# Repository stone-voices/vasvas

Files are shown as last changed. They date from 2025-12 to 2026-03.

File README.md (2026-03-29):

# VasVas Noisebox

Noisebox with FX Processor based on Daisy Seed microcontroller. 

Demo Video (https://www.youtube.com/watch?v=F5kSkdeNpbo)

This noise box has two piezo pickups, the signal from which falls into the left and right channels, respectively, which allows you to get a real stereo signal at the output. In firmware version 1.0, the effects processor includes a reverb based on the Dattorro algorithm and a Shimmer effect that extracts the second harmonic from the signal. A special feature of the reverb is the presence of delay lines and all-pass filters with proportionally variable sizes, as well as a long decay, which can be switched to freezing mode to obtain an undamped reverberation.
In future versions, some changes in the effects used are possible, although this will only affect the software, leaving the hardware unchanged.

This repository includes the circuit diagram and KiCad design files for the PCB, as well as the source code, including all the libraries needed for building.

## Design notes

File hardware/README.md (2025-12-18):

# Hardware

This directory contains the KiCad files for manufacturing the VasVas Noisebox PCB. Includes schematic, pcb, and BOM.

## VasVas Noisebox base

The VasVas Noisebox base uses a plywood case with the following characteristics:
- Stereo output as two separate jacks. One of them can be used as a stereo (left channel) if the right channel jack is not connected.
- 9..15v power
- 4 potentiometer knobs 
- 1 push button
- 2 LEDs

As for the elements that create mechanical vibrations, you can use them at your discretion. These can be compression and tension springs, various plates, gongs, tuning forks, spinners, radiators and other sources of vibrations. Appropriate fasteners must also be used to secure these elements in the form of bolts, nuts, washers, self-tapping screws, etc.

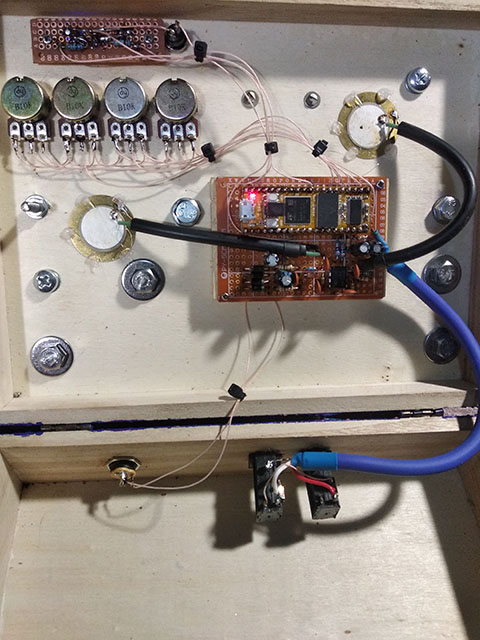
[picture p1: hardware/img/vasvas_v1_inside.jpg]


The electrical circuits are mounted by soldering using a MGTF mounting wire (stranded copper wire with fluoroplastic insulation) with a cross section of 0.07 square mm. The output connectors and piezoelectric elements are connected by a shielded wire to reduce interference. The piezoelectric elements are attached to the body by gluing with an adhesive gun with nylon rods.

The prototype was assembled using a 70 x 50 mm breadboard.

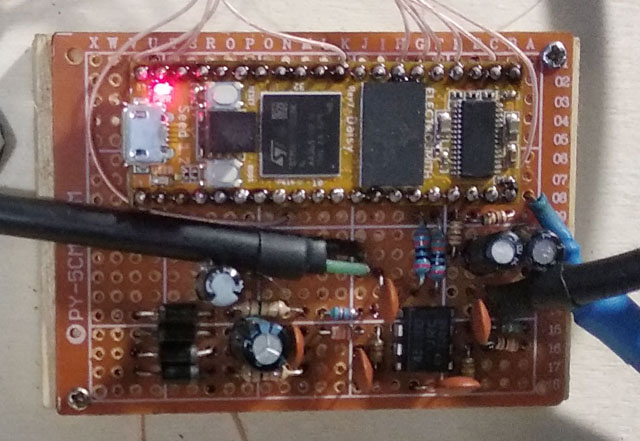
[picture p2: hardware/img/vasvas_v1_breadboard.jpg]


The LEDs, together with current-limiting resistors, are mounted on a small piece of a breadboard.

The layout of the elements is very arbitrary, so you can change it at your discretion based on your needs.

### Some remarks

You can change the schematic diagram of the pre-amplification stage by changing the brand of the operational amplifier to a higher-quality one, or abandon it altogether by replacing it with an amplification stage on a field-effect or bipolar transistor.

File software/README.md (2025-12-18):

# Software

Software for the VasVas Noisebox platform.
So far only version 1.0.

Compilation and assembly was carried out in Visual Studio Code.

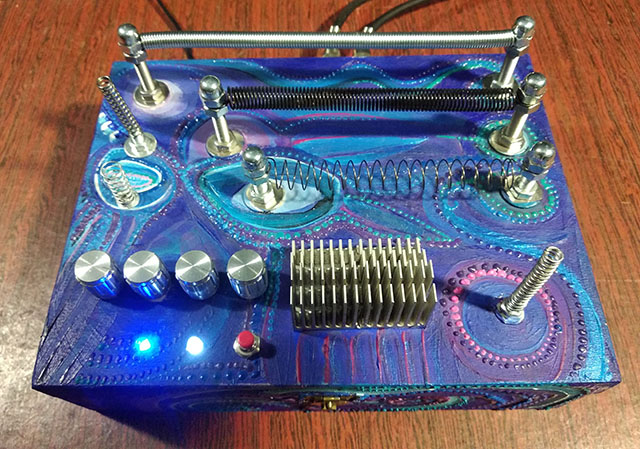
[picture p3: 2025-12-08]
hardware/img/vasvas_v1_front.jpg

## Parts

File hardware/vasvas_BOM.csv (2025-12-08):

Item | Reference(s) | Value
1 | A1 | Electrosmith Daisy Seed Rev7
2 | J4/J5 | 01x20 Socket or DIP40 Socket 15.24mm 2.54mm
3 | U1 | 4580DD
4 | Y1 | Piezo disk 27mm
5 | Y2 | Piezo disk 27mm
6 | HL1 | LED blue
7 | HL2 | LED white
8 | SW1 | Button ST-304B
9 | J1 | Power Jack DC 5.5 x 2.5
10 | J2 | Audio Jack stereo 6.3 mm
11 | J3 | Audio Jack stereo 6.3 mm
12 | RV1 | Potentiometer 10K B
13 | RV2 | Potentiometer 10K B
14 | RV3 | Potentiometer 10K B
15 | RV4 | Potentiometer 10K B
16 | R1 | Resistor 0.125w 10K
17 | R2 | Resistor 0.125w 10K
18 | R3 | Resistor 0.125w 100K
19 | R4 | Resistor 0.125w 100K
20 | R5 | Resistor 0.125w 10K
21 | R6 | Resistor 0.125w 10K
22 | R7 | Resistor 0.125w 100K
23 | R8 | Resistor 0.125w 100K
24 | R9 | Resistor 0.125w 100K
25 | R10 | Resistor 0.125w 100K
26 | R11 | Resistor 0.125w 510
27 | R12 | Resistor 0.125w 510
28 | R13 | Resistor 0.125w 220
29 | R14 | Resistor 0.125w 220
30 | C1 | Electrolytic capacitor 100µFx25v
31 | C2 | Ceramic capacitor 100nF
32 | C3 | Electrolytic capacitor 100µFx16v
33 | C4 | Ceramic capacitor 100nF
34 | C5 | Ceramic capacitor 100nF
35 | C6 | Ceramic capacitor 100nF
36 | C7 | Ceramic capacitor 100nF
37 | C8 | Electrolytic capacitor 22µFx16v BP
38 | C9 | Electrolytic capacitor 22µFx16v BP
39 | D1 | 1N4004
40 | D2 | 1N4004
41 | D3 | 1N4004
42 | D4 | 1N4004

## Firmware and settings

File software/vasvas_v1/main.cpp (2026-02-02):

#include "daisy_petal.h"
#include "daisysp.h"

#include "tools.h"
#include "reverb.h"
#include "fastsin.h"
#include <q/support/literals.hpp>
#include <q/fx/biquad.hpp>
#include "multirate.h"
#include "octaver.h"

#define BUFFER_SIZE 48
#define LED_1 22
#define FOOTSWITCH_1 0
#define FOOTSWITCH_2 1
#define KNOB_1 4
#define	KNOB_2 2
#define	KNOB_3 0
#define	KNOB_4 1

namespace q = cycfi::q;
using namespace q::literals;

using namespace daisy;
using namespace daisysp;


DaisyPetal hw;
Parameter rsize, mix, rdecay, shimmer;
float psize, pmix, pdecay, pshimmer;
float vmix, vdecay, vsize, vshimmer;
Led led1;

float dryMix = 1;
float wetMix = 0;

TReverb reverb;

bool freeze = false;

static const auto sample_rate_temp = 48000; //hard code for now 
static Decimator2 decimate;
static Interpolator interpolate; 
static OctaveGenerator octave(sample_rate_temp / resample_factor); // resample_factor is defined in Multirate.h and equals 6
static q::highshelf eq1(-11, 140_Hz, sample_rate_temp);
static q::lowshelf eq2(5, 160_Hz, sample_rate_temp);   // NOTE: the sample_rate must be divisible by the resample_factor (48/6 = 8)

float buff[6];
float buff_out[6];
int bin_counter = 0;

bool KnobMoved(float old_value, float new_value)
{
    float tolerance = 0.005f;
    if (new_value > (old_value + tolerance) || new_value < (old_value - tolerance)) 
        return true;
    else 
        return false;
}

void UpdateButtons()
{
    if (hw.switches[FOOTSWITCH_1].FallingEdge())
    {
      freeze = !freeze;
			reverb.SetFreeze(freeze);	
    }

    led1.Set(freeze ? 1.0f : 0.0f); 
}


// This runs at a fixed rate, to prepare audio samples
static void AudioCallback(AudioHandle::InputBuffer  in,
                          AudioHandle::OutputBuffer out,
                          size_t                    size)
{

    hw.ProcessAnalogControls();
    hw.ProcessDigitalControls();
    led1.Update();

    UpdateButtons();


    vdecay = rdecay.Process();
		vsize = rsize.Process();
		vshimmer = shimmer.Process();
    vmix = mix.Process();

    if (pmix != vmix) 
		{
        if (KnobMoved(pmix, vmix)) 
				{
            //    A cheap mostly energy constant crossfade from SignalSmith Blog
            float x2 = 1.0 - vmix;
            float A = vmix * x2;
            float B = A * (1.0f + 1.4186f * A);
            float C = B + vmix;
            float D = B + x2;

            wetMix = C * C;
            dryMix = D * D;
            pmix = vmix;
        }
    }


    if (KnobMoved(pdecay, vdecay)) 
		{
        pdecay = vdecay;
				reverb.SetDecay(vdecay);
    }


    if (KnobMoved(psize, vsize)) 
		{      
        psize = vsize;    
				reverb.SetSize(vsize);
    }
		
		if (KnobMoved(pshimmer, vshimmer)) 
		{
        pshimmer = vshimmer;
    }

    float inputL;
    float inputR;

    for (size_t i = 0; i < size; ++i)
    {

        inputL = in[0][i];
        inputR = in[1][i];
 
        // NOTE: Octave before reverb sounds better (personal preference), and doing octave after reverb would require another polyoctave for second channel anyway
        buff[bin_counter] = (inputL + inputR) * 0.5f;
        // do calculation every 6 samples
        if (bin_counter > 4) 
				{

            std::span<const float, resample_factor> in_chunk(&(buff[0]), resample_factor);  // std::span is c++ 20 feature
                
            const auto sample = decimate(in_chunk); 
  
            octave.update(sample);

            float octave_mix = pshimmer * octave.up1() * 2.0;

            auto out_chunk = interpolate(octave_mix);
            for (size_t j = 0; j < out_chunk.size(); ++j)
            {
                float mix = eq2(eq1(out_chunk[j]));        
                mix += 0.5 * buff[j]; 
                buff_out[j] = mix;    
            }

        }
                // Sets increments the buffer index from 0 to 5 (workaround to adapt code)
        bin_counter += 1;
        if (bin_counter > 5)
            bin_counter = 0;

        float reverb_in = buff_out[bin_counter]; 
        float outL, outR;
        reverb.Process(reverb_in, outL, outR);


      out[0][i] = in[0][i] * dryMix + outL * wetMix; 
      out[1][i] = in[1][i] * dryMix + outR * wetMix;
    }
}

int main(void)
{
    hw.Init(true);
    float samplerate;
    samplerate = hw.AudioSampleRate();

    TFastSin::Initialize();
   

		vmix = vdecay = vsize = vshimmer = 0.0;
		pmix = pdecay = psize = pshimmer = 0.0;
		
		reverb.SetSampleRate(samplerate);

    hw.SetAudioBlockSize(BUFFER_SIZE);

    // Initialize buffers to 0
    for (int j = 0; j < 6; ++j) 
	  {
        buff[j] = 0.0;
        buff_out[j] = 0.0;
    }

    rdecay.Init(hw.knob[KNOB_1], 1.0f, 100.0f, Parameter::EXPONENTIAL);
		rsize.Init(hw.knob[KNOB_2], 0.5f, 2.5f, Parameter::EXPONENTIAL);
		shimmer.Init(hw.knob[KNOB_3], 0.0f, 1.0f, Parameter::LINEAR);
    mix.Init(hw.knob[KNOB_4], 0.0f, 1.0f, Parameter::LINEAR);
		   

    led1.Init(hw.seed.GetPin(LED_1),false);
    led1.Update();
    

    hw.StartAdc();
    hw.StartAudio(AudioCallback);
    while(1)
    {
	    System::Delay(100);
    }
}

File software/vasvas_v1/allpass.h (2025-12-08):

#pragma once

#include "delaybase.h"

class TStaticAllPass : public TDelayCell
{
protected:
  float fFeedback = 0;
  int fDelay = 0;
public:
  void SetParams(float samplerate, float delay, float feedback);
  float Process(float sample);
};

class TResizedAllPass : public TDelayCell
{
private:
  float fDelay = 0;
public:
  void SetParams(float samplerate, float delay);
  float Process(float sample, float feedback, float sizecoeff);
};

class TModulatedAllPass : public TDelayCell
{
private:
  float fLfoInc = 0;
  float fLfoAngle = 0;
  float fDepth = 0;
  float fDelay = 0;
  const float fFeedback = 0.7f;
public:
  void SetParams(float samplerate, float delay, float rate, float depth);
  float Process(float sample, float sizecoeff);
};
